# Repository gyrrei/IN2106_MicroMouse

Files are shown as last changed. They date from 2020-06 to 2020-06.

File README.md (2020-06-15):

# MicroMouse - Advanced Practical Course

IN2106 @TUM SS19 by Prof. Alexander Lenz. Achieved a 1.0 grade.

Master practical course - Micromouse: Designing an Educational Racing-Robot from Scratch. The purpose is for the students to build an electrical micro mouse from scratch and program it to explore a mace and find the fastest way to a goal.

The src has five folders:
- Bluetooth; describes the bluetooth module
- Code; the source code with headers and c files
- Notes; papers gathered and used throughout the project
- Micromouse_board; files describing the board design 
- Motormount; files describing the design of the motormounts

Read more about the course here: https://campus.tum.de/tumonline/wbLv.wbShowLVDetail?pStpSpNr=950367380&pSpracheNr=2

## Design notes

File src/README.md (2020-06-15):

# The source code
This project is organised as a practical course at the Technical University Munich for the students at the department of informatics. The purpose is for the students to build an electrical micro mouse from scratch and program it to explore a mace and find the fastest way to a goal.

### Here you find 5 folders:
- Bluetooth; describes the bluetooth module
- Code; the source code with headers and c files
- Notes; papers gathered and used throughout the project
- Micromouse_board; files describing the board design 
- Motormount; files describing the design of the motormounts

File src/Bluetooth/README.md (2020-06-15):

# Bluetooth laptop interface

## To run double-click:

	Bluetooth.jar 

## Use:

1. Select Bluetooth device
2. Select SERIAL service 
3. get UPDATE with pressing 'U'
   get periodic UPDATEs with pressing 'P'
   stop periodic UPDATEs with pressing 'Q'

## Requirements

Java 11

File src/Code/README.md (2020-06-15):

# Code

## Sensors

### ADC

takes the sensor input from AN0, 1 and 4 

### DMA

transfers these values to adcData[0], adcData[1] and adcData[2]

### Sensor

can return if there's a wall detected and how far away the walls are

## Motor

### PWM

Motors driving forward, backward, stop

### QEI

get the encoder signal -> calculating speed and distance

### Control

PID controler to keep the angular speed as it should
Speed of Motor 1 (negativ), Motor 2 (positiv) --> mounted the other way round

## Communication

## UART

can send String messages via bluetooth module

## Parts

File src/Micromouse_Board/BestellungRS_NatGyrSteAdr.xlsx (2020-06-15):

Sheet: Bestellung
Lieferant: RS
https://www.mouser.de/
 | Bestellnummer | Description | Need | Min order | Single price | Total price
 | 915-5193 | TDK, CGA SMD MLCC, Vielschicht Keramikkondensator X7S, 10μF ±10% / 16Vdc, 125°C, Gehäuse 0805 (2012M) | 2 | 20 | 0.24 € | 4.90 €
 | 885-1691 | Murata, GRM SMD MLCC, Vielschicht Keramikkondensator X5R, 22μF ±20% / 16Vdc, Gehäuse 0805 (2012M) | 2 | 20 | 0.29 € | 5.88 €
 | 825-6949 | Texas Instruments TPS62163DSGT Abwärtswandler, 2,25 MHz / 1A, WSON 8-Pin, Fest | 1 | 5 | 1.81 € | 9.05 €
 | 825-6945 | Texas Instruments TPS62162DSGT Abwärtswandler, 2,25 MHz / 1A, WSON 8-Pin, Fest | 1 | 5 | 1.81 € | 9.05 €
 | 123-3126 | TDK SPM-LR Drosselspule mit Metall-Kern geschirmt, 2,2 μH / ±20% 2,6A, 3012 Gehäuse | 2 | 10 | 0.30 € | 3.00 €
 | 435-6767 | Broadcom SMD LED grün 2,2 V, 170° rechteckige Linse 2012 / 0805 | 3 | 50 | 0.24 € | 12.25 €
 | 565-869 | Panasonic ERA Dünnschichtwiderstand, 150Ω ±0.1% 0,125W, 0805 | 1 | 5 | 0.29 € | 1.45 €
 | 740-8971 | Bourns CR0805 SMD Festwiderstand, 1kΩ ±1% 0,125W, 0805 | 1 | 50 | 0.03 € | 1.45 €
 | 679-1608 | Vishay CRCW SMD Dickschichtwiderstand, 62Ω ±1% 0,125W, 0805 | 1 | 50 | 0.04 € | 2.25 €
 | 773-8446 | Syfer Technology, Flexicap SMD MLCC, Vielschicht Keramikkondensator C0G, NP0, 22pF ±5% / 100Vdc, 125°C | 2 | 10 | 0.13 € | 1.34 €
 | 391-5371 | Susumu Co Dünnschichtwiderstand, 47kΩ ±0.5% 0,063W, 0603 | 1 | 100 | 0.02 € | 2.30 €
 | 708-2197 | 1N5819HW-7-F Schottky Diode, 40V / 1A, SOD-123 2-Pin | 9 | 25 | 0.25 € | 6.30 €
 | 135-9548 | C & K PTS645SM502 LFS Taster, Einpoliger Ein/Aus-Schalter (SPST) 50 mA, 6 x 6mm | 2 | 20 | 0.17 € | 3.38 €
 | 146-0786 | Sharp Reflektierender Sensor, Oberflächenmontage, 15cm, 27 x 13.2 x 12mm | 3 | 3 | 6.97 € | 20.91 €
 | 714-0613 | Motor Driver IC L293B, 1A PDIP 16-Pin 4,5 → 36 V | 1 | 1 | 3.21 € | 3.21 €
 | 174-4482 | KEMET, C0805 SMD MLCC, Vielschicht Keramikkondensator X7R, 100nF ±10% / 100Vdc, 125°C, Gehäuse 0805 | 4 | 100 | 0.11 € | 10.80 €
 | 136-6079 | AVX TPS SMD Tantal Elko, Kondensator, 10μF ±10%, 20Vdc, +125°C, Gehäuse 3528-21 | 1 | 10 | 0.64 € | 6.43 €
 | 740-8971 | Bourns CR0805 SMD Festwiderstand, 1kΩ ±1% 0,125W, 0805 | 2 | 50 | 0.03 € | 1.45 €
 | 671-0453 | PowerTrench FDN359BN N-Kanal MOSFET, 30 V / 2,7 A, 500 mW, SOT-23 3-Pin | 1 | 5 | 0.40 € | 2.02 €
 | 566-412 | Panasonic ERA Dünnschichtwiderstand, 180Ω ±0.1% 0,1W, 0603 | 1 | 5 | 0.29 € | 1.47 €
 |  |  |  |  | Gesamtsumme: | 108.89 €

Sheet: All info
 | Lieferant: RS
 | https://www.mouser.de/
Same hersteller no? | Mouser no. | RS no. | Part no. | Part description | Bestellnummer | Beschreibung | Only need | Menge | Einzelpreis | Gesamtpreis | Mouserlink
FALSE | dsPIC33FJ64MC804-H/PT | dsPIC33FJ64MC804-I/PT | Is this double? See dspic further down | uc | 666-8491 | Digitaler Signalprozessor 16bit 40MHz 16 KB 64 KB Flash, TQFP 44-Pin 9-Kanal x 10 Bit, 9-Kanal x 12 Bit ADC, 1 1 2 | 1 | 1 | 4.76 € | 4.76 € | https://www.mouser.de/ProductDetail/Microchip-Technology/dsPIC33FJ64MC804-H-PT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
FALSE | CGA4J1X7S1E106K125AC | CGA4J1X7S1C106K125AC | c1 | cap 10u | 915-5193 | TDK, CGA SMD MLCC, Vielschicht Keramikkondensator X7S, 10μF ±10% / 16Vdc, 125°C, Gehäuse 0805 (2012M) | 2 | 20 | 0.24 € | 4.90 € | https://www.mouser.de/ProductDetail/TDK/CGA4J1X7S1E106K125AC
FALSE | GRM219R61C226ME15K | GRM219R61C226ME15L | c2 | cap 22u | 885-1691 | Murata, GRM SMD MLCC, Vielschicht Keramikkondensator X5R, 22μF ±20% / 16Vdc, Gehäuse 0805 (2012M) | 2 | 20 | 0.29 € | 5.88 € | https://www.mouser.de/ProductDetail/Murata-Electronics/GRM219R61C226ME15K
FALSE | TPS62163DSGR | TPS62163DSGT | u1 | tps62163 | 825-6949 | Texas Instruments TPS62163DSGT Abwärtswandler, 2,25 MHz / 1A, WSON 8-Pin, Fest | 1 | 5 | 1.81 € | 9.05 € | https://www.mouser.de/ProductDetail/Texas-Instruments/TPS62163DSGR
FALSE | TPS62162QDSGRQ1 | TPS62162DSGT | u2 | tps62162 | 825-6945 | Texas Instruments TPS62162DSGT Abwärtswandler, 2,25 MHz / 1A, WSON 8-Pin, Fest | 1 | 5 | 1.81 € | 9.05 € | https://www.mouser.de/ProductDetail/Texas-Instruments/TPS62162QDSGRQ1
TRUE | VLS3012HBX-2R2M | VLS3012HBX-2R2M | L1,L2 | ind | 181-5236 | TDK VLS-HBX Drosselspule mit Metall-Kern geschirmt, 2,2 μH / ±20% 3.76A | 2 | 250 | 0.49 € | 122.50 € | https://www.mouser.de/ProductDetail/?qs=pfd5qewlna6oSgcfnWnTMg%3D%3D
 | Alternative with a bit higher max DC 8,2A | 7448991022 | L1,L2 | ind | 185-7300 | Würth WE-MCRI SMD Induktivität mit Sinterstahl-Kern geschirmt, 2,2 μH / ±20%, 21.5MHz 8,2A, SMT Gehäuse | 2 | 2 | 3.40 € | 6.80 €
FALSE | HSME-C170 | HSMG-C170 | led1,led2,led3 | leds | 435-6767 | Broadcom SMD LED grün 2,2 V, 170° rechteckige Linse 2012 / 0805 | 3 | 50 | 0.24 € | 12.25 € | https://www.mouser.de/ProductDetail/Broadcom-Avago/HSME-C170?qs=sGAEpiMZZMseGfSY3csMkcu5vLJdOE0s5hBoS5UZEy4%3D
FALSE | RT0805FRE13150RL | ERA6AEB151V | r1 | res 150 | 565-869 | Panasonic ERA Dünnschichtwiderstand, 150Ω ±0.1% 0,125W, 0805 | 1 | 5 | 0.29 € | 1.45 € | https://www.mouser.de/ProductDetail/Yageo/RT0805FRE13150RL
FALSE | CR0805-FX-62R0ELF | CR0805-FX-1001ELF | r2 | res 62 | 740-8971 | Bourns CR0805 SMD Festwiderstand, 1kΩ ±1% 0,125W, 0805 | 1 | 50 | 0.03 € | 1.45 € | https://www.mouser.de/ProductDetail/Bourns/CR0805-FX-62R0ELF
FALSE | FOXSDLF/160R-20/TR | CRCW080562R0FKEA | y1 | 16mhz osc | 679-1608 | Vishay CRCW SMD Dickschichtwiderstand, 62Ω ±1% 0,125W, 0805 | 1 | 50 | 0.04 € | 2.25 € | https://www.mouser.de/ProductDetail/Fox/FOXSDLF-160R-20-TR
FALSE |  | 0603Y1000220JCT | c5,c6 | cap 22pF | 773-8446 | Syfer Technology, Flexicap SMD MLCC, Vielschicht Keramikkondensator C0G, NP0, 22pF ±5% / 100Vdc, 125°C | 2 | 10 | 0.13 € | 1.34 € | https://de.rs-online.com/web/p/mehrschichtkeramikkondensatoren/7738446/
FALSE | RS2012P-473-D-T5-3 | RR0816P-473-D | r3 | res 47k | 391-5371 | Susumu Co Dünnschichtwiderstand, 47kΩ ±0.5% 0,063W, 0603 | 1 | 100 | 0.02 € | 2.30 € | https://www.mouser.de/ProductDetail/Susumu/RS2012P-473-D-T5-3
TRUE | 1N5819HW-7-F | 1N5819HW-7-F | d1..9 | diode | 708-2197 | 1N5819HW-7-F Schottky Diode, 40V / 1A, SOD-123 2-Pin | 9 | 25 | 0.25 € | 6.30 € | https://www.mouser.de/ProductDetail/Diodes-Incorporated/1N5819HW-7-F
FALSE | PTS647SM50SMTR2LFS | PTS645SM502LFS | s1,s2 | switch | 135-9548 | C & K PTS645SM502 LFS Taster, Einpoliger Ein/Aus-Schalter (SPST) 50 mA, 6 x 6mm | 2 | 20 | 0.17 € | 3.38 € | https://www.mouser.de/ProductDetail/CK/PTS647SM50SMTR2LFS
FALSE |  | GP2Y0A51SK0F | j3,j4,j5 | dist sens | 146-0786 | Sharp Reflektierender Sensor, Oberflächenmontage, 15cm, 27 x 13.2 x 12mm | 3 | 3 | 6.97 € | 20.91 € | https://de.rs-online.com/web/p/reflexions-lichtschranke/1460786/
TRUE | L293B | L293B | ic1 | hbridge | 714-0613 | Motor Driver IC L293B, 1A PDIP 16-Pin 4,5 → 36 V | 1 | 1 | 3.21 € | 3.21 € | https://www.mouser.de/ProductDetail/STMicroelectronics/L293B?qs=sGAEpiMZZMutXGli8Ay4kJRAwT4cotuJVvdz57xMrNY%3D
TRUE | C0805C104K1RECAUTO | C0805C104K1RECAUTO | c7,9,10,11 | dec cap 0.1u | 174-4482 | KEMET, C0805 SMD MLCC, Vielschicht Keramikkondensator X7R, 100nF ±10% / 100Vdc, 125°C, Gehäuse 0805 | 4 | 100 | 0.11 € | 10.80 € | https://www.mouser.de/ProductDetail/KEMET/C0805C104K1RECAUTO
TRUE | dsPIC33FJ64MC804-I/PT | dsPIC33FJ64MC804-I/PT |  | dspic | 666-8491 | Digitaler Signalprozessor 16bit 40MHz 16 KB 64 KB Flash, TQFP 44-Pin 9-Kanal x 10 Bit, 9-Kanal x 12 Bit ADC, 1 1 2 | 1 | 1 | 4.76 € | 4.76 € | https://www.mouser.de/ProductDetail/Microchip-Technology/dsPIC33FJ64MC804-I-PT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
FALSE | TPSB106K025T1800 | TPSB106K020R1000 | c8 | vcap 10uf | 136-6079 | AVX TPS SMD Tantal Elko, Kondensator, 10μF ±10%, 20Vdc, +125°C, Gehäuse 3528-21 | 1 | 10 | 0.64 € | 6.43 € | https://www.mouser.de/ProductDetail/AVX/TPSB106K025T1800
FALSE |  | CR0805-FX-1001ELF | r5,r7 | res 1k | 740-8971 | Bourns CR0805 SMD Festwiderstand, 1kΩ ±1% 0,125W, 0805 | 2 | 50 | 0.03 € | 1.45 € | https://de.rs-online.com/web/p/smd-widerstande/7408971/
FALSE |  | FDN359BN | t1 | mosfet | 671-0453 | PowerTrench FDN359BN N-Kanal MOSFET, 30 V / 2,7 A, 500 mW, SOT-23 3-Pin | 1 | 5 | 0.40 € | 2.02 € | https://de.rs-online.com/web/p/mosfet/6710453/?searchHistory=%7B%22enabled%22%3Atrue%7D
FALSE |  | ERA3AEB181V | r6 | res 180 | 566-412 | Panasonic ERA Dünnschichtwiderstand, 180Ω ±0.1% 0,1W, 0603 | 1 | 5 | 0.29 € | 1.47 €
 |  |  |  |  |  |  |  |  | Gesamtsumme: | 244.72 €

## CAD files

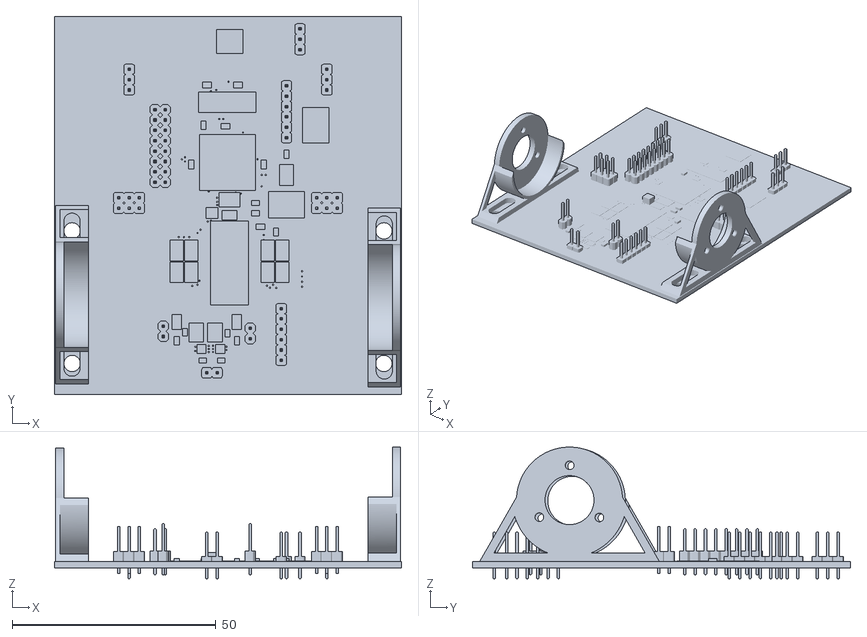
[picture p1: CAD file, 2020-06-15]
src/Motormount/micro_schematic v3.stl
85.1 x 92.7 x 32.3

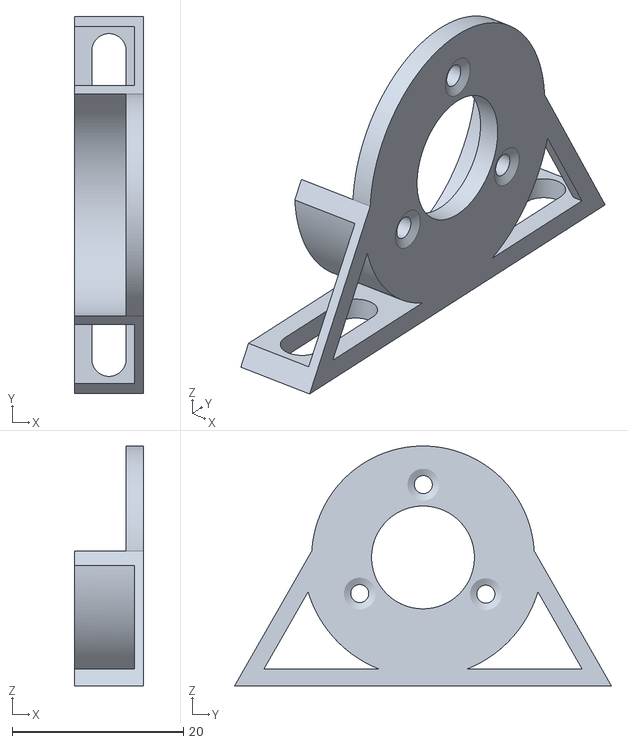
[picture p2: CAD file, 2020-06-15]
src/Motormount/mount.stl
8.00 x 44.0 x 28.0

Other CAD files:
src/Motormount/mount.f3d

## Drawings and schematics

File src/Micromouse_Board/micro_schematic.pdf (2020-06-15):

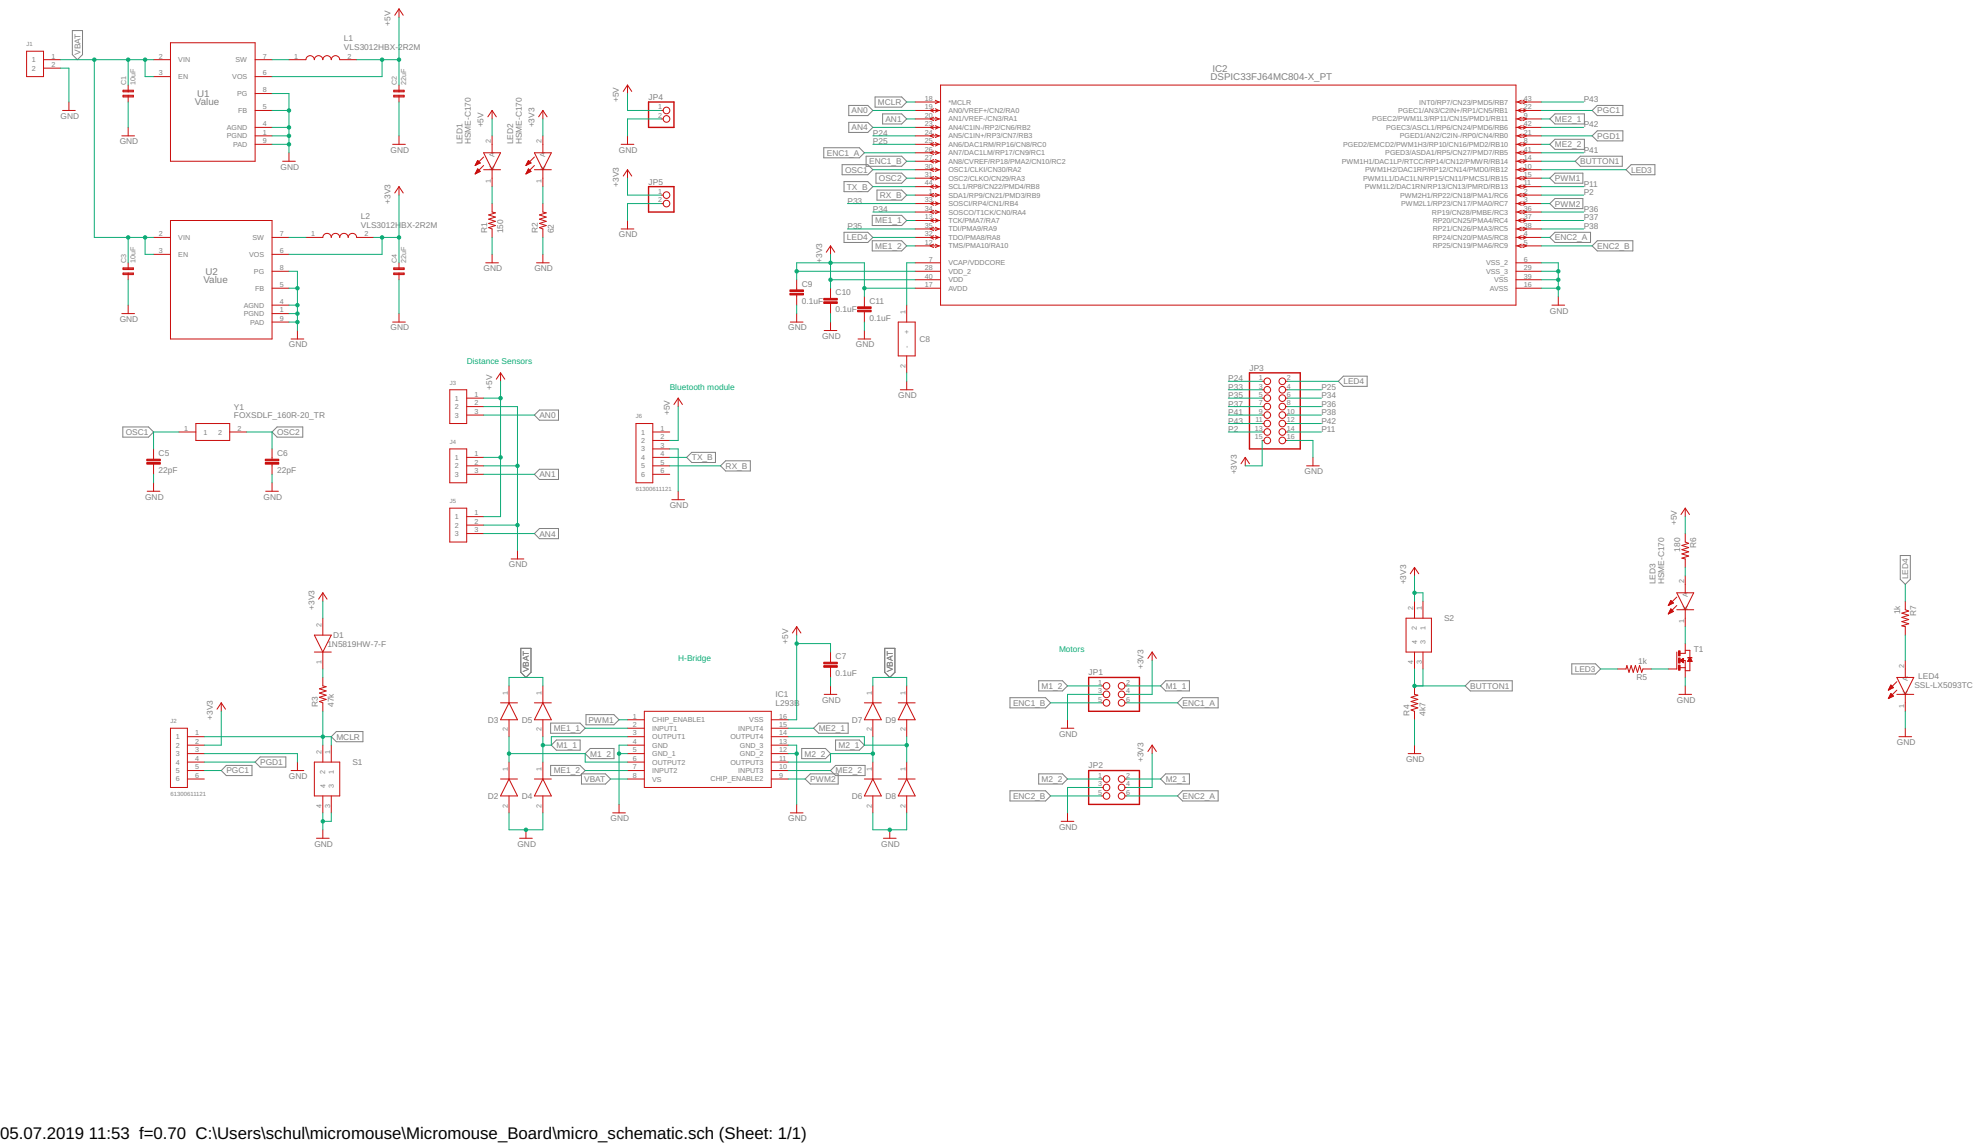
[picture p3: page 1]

05.07.2019 11:53 f=0.70 C:\Users\schul\micromouse\Micromouse_Board\micro_schematic.sch (Sheet: 1/1)

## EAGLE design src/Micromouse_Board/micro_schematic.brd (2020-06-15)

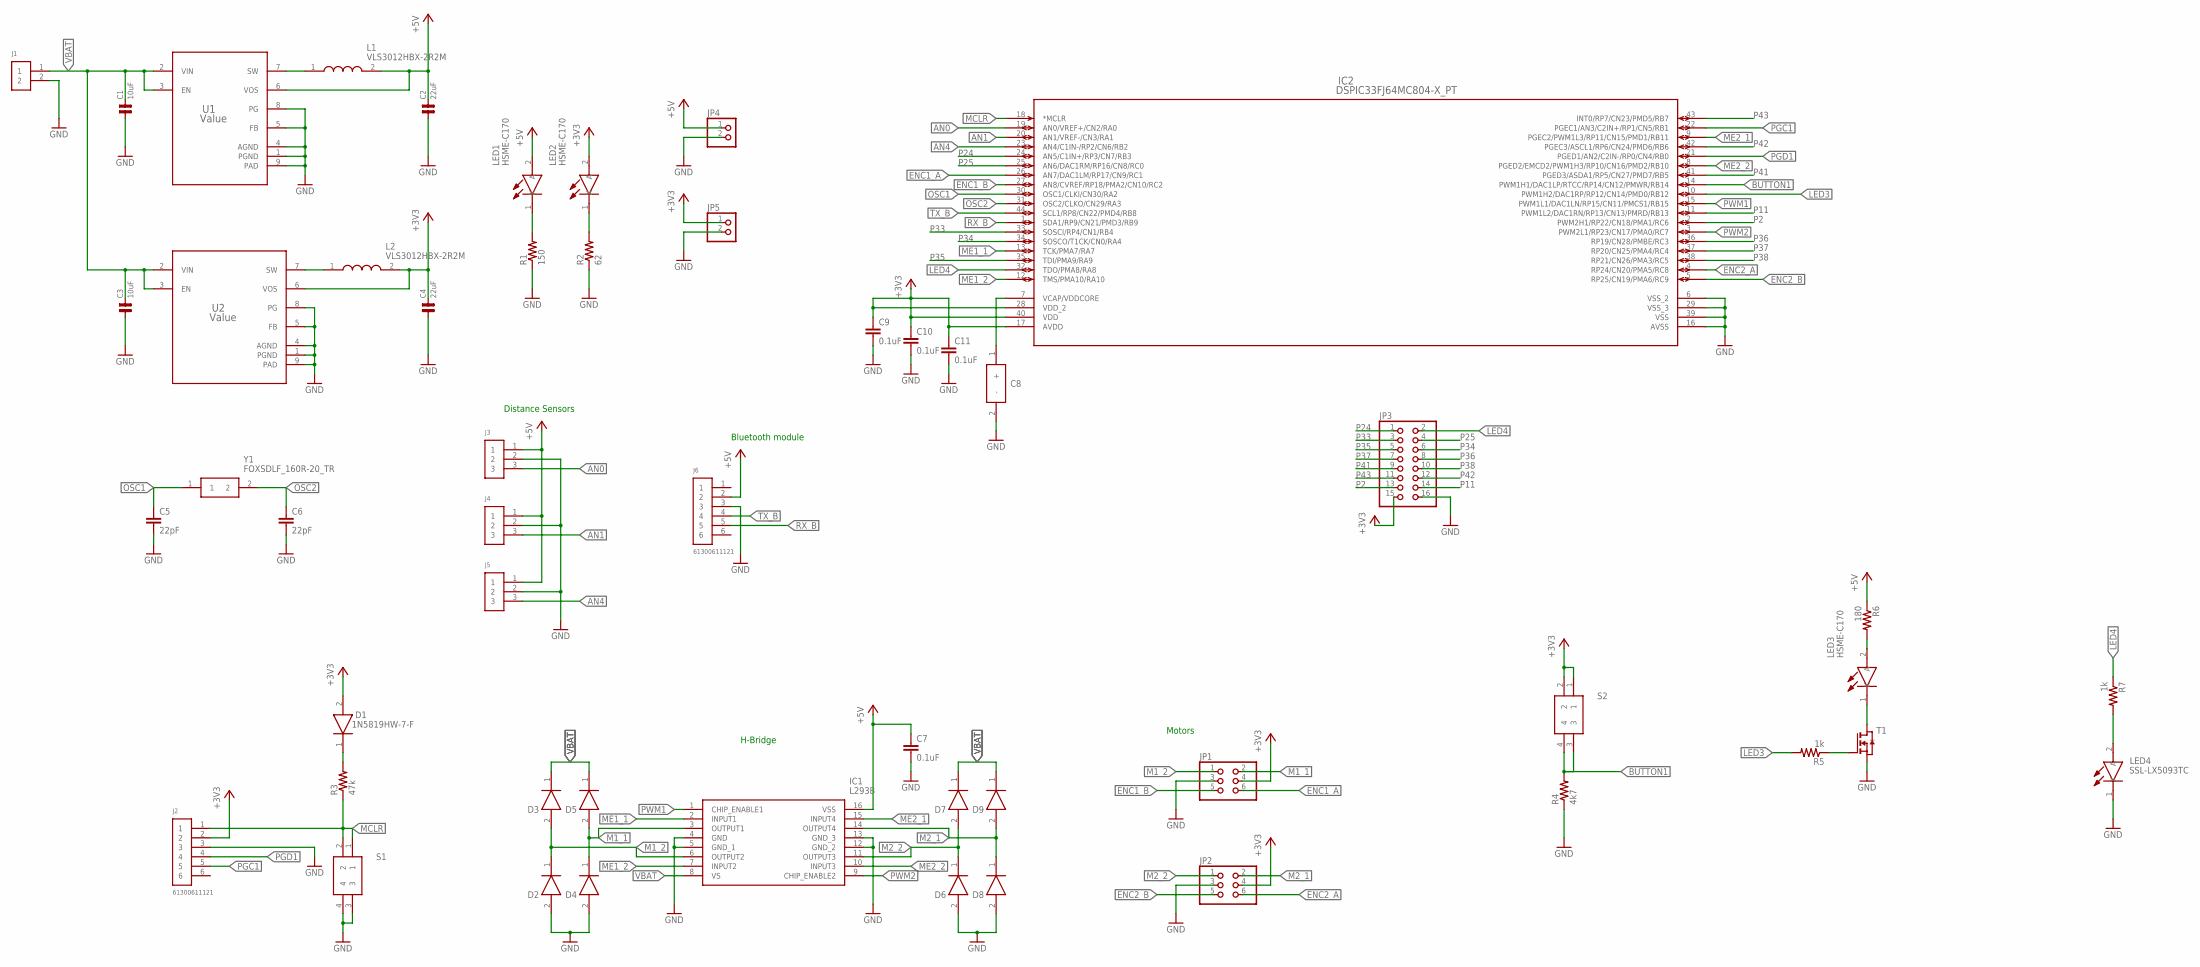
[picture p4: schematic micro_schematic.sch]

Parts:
C1, C3: 10uF; 0805
C2, C4: 22uF; 0805
C5, C6: 22pF; C0805
C7, C9, C10, C11: 0.1uF; C0805
C8: TPSB106K025T1800; DIONM3528X210N
D1, D2, D3, D4, D5, D6, D7, D8, D9: 1N5819HW-7-F; SOD3716X145N
IC1: L293B; DIP780W50P254L2000H510Q16N
IC2: DSPIC33FJ64MC804-X_PT; TQFP44_10X10MC
J1: 61300211121
J2, J6: 61300611121
J3, J4, J5: 61300311121
JP1, JP2: PINHD-2X3; 2X03
JP3: PINHD-2X8; 2X08
JP4, JP5: PINHD-1X2; 1X02
L1, L2: VLS3012HBX-2R2M; INDPM3030X120N
LED1, LED2, LED3: HSME-C170; LEDC2012X90N
LED4: SSL-LX5093TC; SSL-LX5093SGC/B
R1: 150; R0805
R2: 62; R0805
R3: 47k; R0805
R4: 4k7; R0805
R5, R7: 1k; R0805
R6: 180; R0805
S1, S2: PTS647SM50SMTR2LFS
T1: NMOSSOT23; SOT-23
U1, U2: Value; DSG0008A
Y1: FOXSDLF_160R-20_TR; FOXSDLF/240F-20

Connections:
+3V3: C4.2, C9.1, C10.1, C11.1, D1.2 (A), IC2.17 (AVDD), IC2.28 (VDD_2), IC2.40 (VDD), J2.2, JP1.4, JP2.4, JP3.15, JP5.1, L2.2, LED2.2 (A), S2.1, S2.2, U2.6 (VOS)
+5V: C2.2, C7.1, IC1.16 (VSS), J3.1, J4.1, J5.1, J6.2, JP4.1, L1.2, LED1.2 (A), R6.1, U1.6 (VOS)
AN0: IC2.19 (AN0/VREF+/CN2/RA0), J3.3
AN1: IC2.20 (AN1/VREF-/CN3/RA1), J4.3
AN4: IC2.23 (AN4/C1IN-/RP2/CN6/RB2), J5.3
BUTTON1: IC2.14 (PWM1H1/DAC1LP/RTCC/RP14/CN12/PMWR/RB14), R4.2, S2.3, S2.4
ENC1_A: IC2.26 (AN7/DAC1LM/RP17/CN9/RC1), JP1.6
ENC1_B: IC2.27 (AN8/CVREF/RP18/PMA2/CN10/RC2), JP1.5
ENC2_A: IC2.4 (RP24/CN20/PMA5/RC8), JP2.6
ENC2_B: IC2.5 (RP25/CN19/PMA6/RC9), JP2.5
GND: C1.1, C2.1, C3.1, C4.1, C5.2, C6.2, C7.2, C8.2 (-), C9.2, C10.2, C11.2, D2.2 (A), D4.2 (A), D6.2 (A), D8.2 (A), IC1.4 (GND), IC1.5 (GND_1), IC1.12 (GND_2), IC1.13 (GND_3), IC2.6 (VSS_2), IC2.16 (AVSS), IC2.29 (VSS_3), IC2.39 (VSS), J1.2, J2.3, J3.2, J4.2, J5.2, J6.3, JP1.3, JP2.3, JP3.16, JP4.2, JP5.2, LED4.1 (K), R1.1, R2.1, R4.1, S1.3, S1.4, T1.2 (S), U1.1 (PGND), U1.4 (AGND), U1.5 (FB), U1.8 (PG), U1.9 (PAD), U2.1 (PGND), U2.4 (AGND), U2.5 (FB), U2.8 (PG), U2.9 (PAD)
LED3: IC2.10 (PWM1H2/DAC1RP/RP12/CN14/PMD0/RB12), R5.2
LED4: IC2.32 (TDO/PMA8/RA8), JP3.2, R7.1
M1_1: D4.1 (K), D5.2 (A), IC1.3 (OUTPUT1), JP1.2
M1_2: D2.1 (K), D3.2 (A), IC1.6 (OUTPUT2), JP1.1
M2_1: D8.1 (K), D9.2 (A), IC1.14 (OUTPUT4), JP2.2
M2_2: D6.1 (K), D7.2 (A), IC1.11 (OUTPUT3), JP2.1
MCLR: IC2.18 (*MCLR), J2.1, R3.1, S1.1, S1.2
ME1_1: IC1.2 (INPUT1), IC2.13 (TCK/PMA7/RA7)
ME1_2: IC1.7 (INPUT2), IC2.12 (TMS/PMA10/RA10)
ME2_1: IC1.15 (INPUT4), IC2.9 (PGEC2/PWM1L3/RP11/CN15/PMD1/RB11)
ME2_2: IC1.10 (INPUT3), IC2.8 (PGED2/EMCD2/PWM1H3/RP10/CN16/PMD2/RB10)
unnamed: C8.1 (+), IC2.7 (VCAP/VDDCORE)
unnamed: LED2.1 (K), R2.2
unnamed: L1.1, U1.7 (SW)
unnamed: LED1.1 (K), R1.2
unnamed: L2.1, U2.7 (SW)
unnamed: R5.1, T1.3 (G)
unnamed: D1.1 (K), R3.2
unnamed: LED3.2 (A), R6.2
unnamed: LED4.2 (A), R7.2
unnamed: LED3.1 (K), T1.1 (D)
OSC1: C5.1, IC2.30 (OSC1/CLKI/CN30/RA2), Y1.1
OSC2: C6.1, IC2.31 (OSC2/CLKO/CN29/RA3), Y1.2
P2: IC2.2 (PWM2H1/RP22/CN18/PMA1/RC6), JP3.13
P11: IC2.11 (PWM1L2/DAC1RN/RP13/CN13/PMRD/RB13), JP3.14
P24: IC2.24 (AN5/C1IN+/RP3/CN7/RB3), JP3.1
P25: IC2.25 (AN6/DAC1RM/RP16/CN8/RC0), JP3.4
P33: IC2.33 (SOSCI/RP4/CN1/RB4), JP3.3
P34: IC2.34 (SOSCO/T1CK/CN0/RA4), JP3.6
P35: IC2.35 (TDI/PMA9/RA9), JP3.5
P36: IC2.36 (RP19/CN28/PMBE/RC3), JP3.8
P37: IC2.37 (RP20/CN25/PMA4/RC4), JP3.7
P38: IC2.38 (RP21/CN26/PMA3/RC5), JP3.10
P41: IC2.41 (PGED3/ASDA1/RP5/CN27/PMD7/RB5), JP3.9
P42: IC2.42 (PGEC3/ASCL1/RP6/CN24/PMD6/RB6), JP3.12
P43: IC2.43 (INT0/RP7/CN23/PMD5/RB7), JP3.11
PGC1: IC2.22 (PGEC1/AN3/C2IN+/RP1/CN5/RB1), J2.5
PGD1: IC2.21 (PGED1/AN2/C2IN-/RP0/CN4/RB0), J2.4
PWM1: IC1.1 (CHIP_ENABLE1), IC2.15 (PWM1L1/DAC1LN/RP15/CN11/PMCS1/RB15)
PWM2: IC1.9 (CHIP_ENABLE2), IC2.3 (PWM2L1/RP23/CN17/PMA0/RC7)
RX_B: IC2.1 (SDA1/RP9/CN21/PMD3/RB9), J6.5
TX_B: IC2.44 (SCL1/RP8/CN22/PMD4/RB8), J6.4
VBAT: C1.2, C3.2, D3.1 (K), D5.1 (K), D7.1 (K), D9.1 (K), IC1.8 (VS), J1.1, U1.2 (VIN), U1.3 (EN), U2.2 (VIN), U2.3 (EN)

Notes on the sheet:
Distance Sensors
Bluetooth module
H-Bridge
Motors

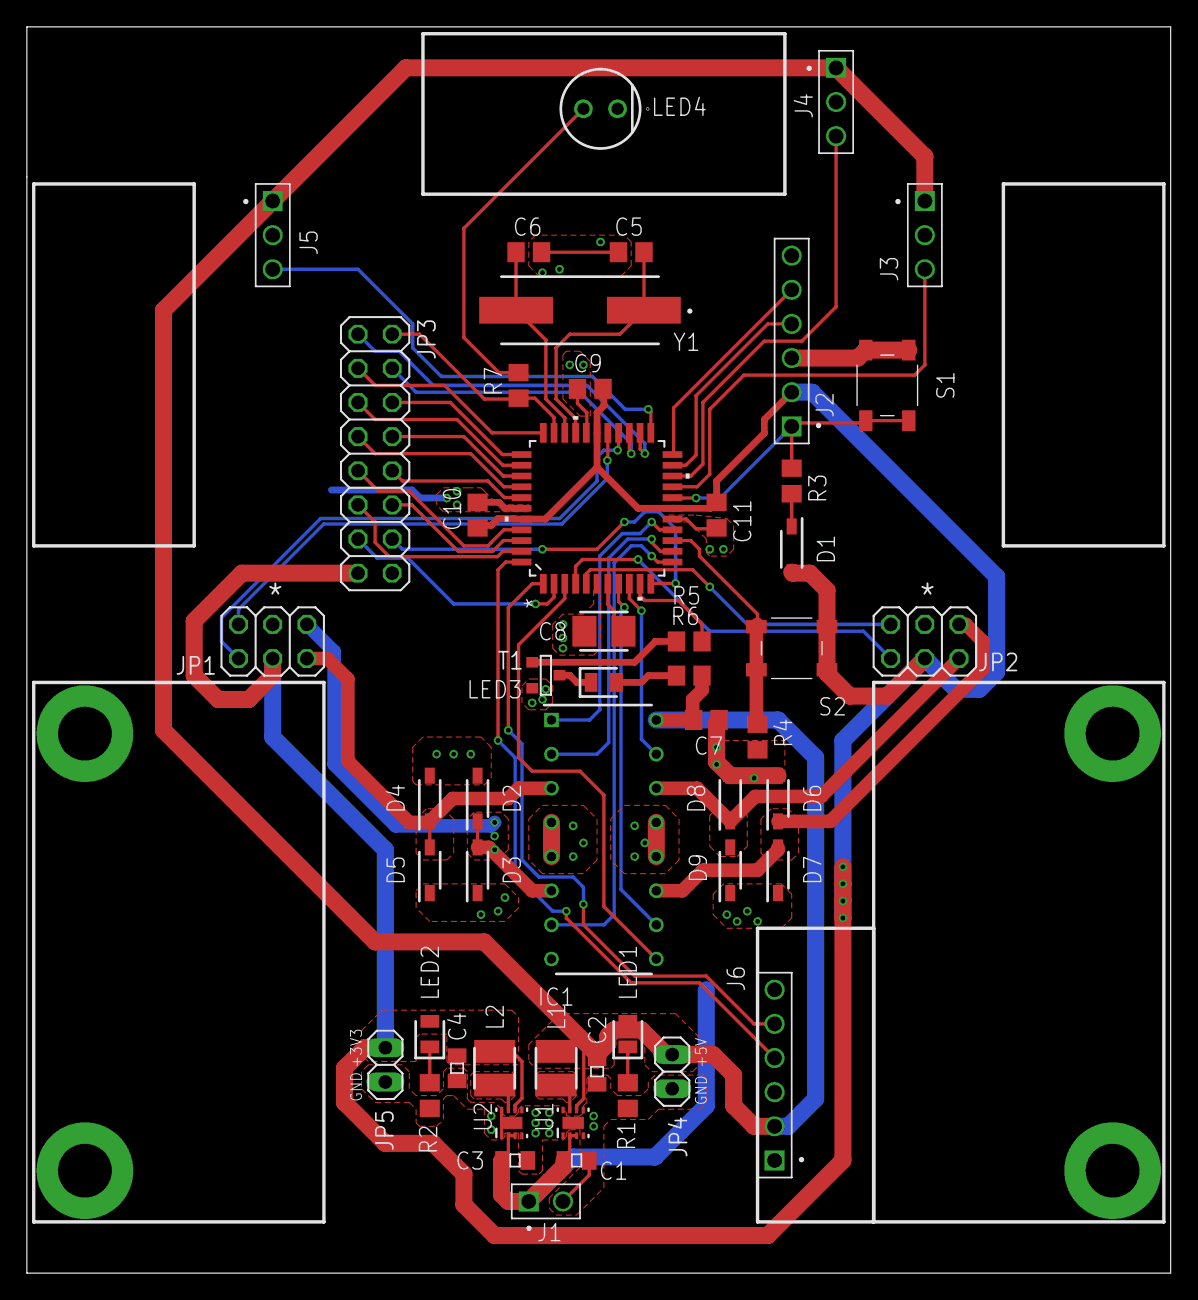
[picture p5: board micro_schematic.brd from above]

Board: 2 copper layers, 85.1 x 92.7 mm, 52 parts (0 on the bottom side), 54 nets.

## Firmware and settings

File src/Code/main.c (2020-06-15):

/*
 * File:   main.c
 * Author: a2-lenz
 *
 * Created on April 5, 2019, 11:20 AM
 */

// FBS
#pragma config BWRP = WRPROTECT_OFF // Boot Segment Write Protect (Boot Segment may be written)
#pragma config BSS = NO_FLASH       // Boot Segment Program Flash Code Protection (No Boot program Flash segment)

// FGS
#pragma config GWRP = OFF // General Code Segment Write Protect (User program memory is not write-protected)
#pragma config GSS = OFF  // General Segment Code Protection (User program memory is not code-protected)

// FOSCSEL
#pragma config FNOSC = PRIPLL // Oscillator Mode (Primary Oscillator (XT, HS, EC) w/ PLL)
#pragma config IESO = ON      // Internal External Switch Over Mode (Start-up device with FRC, then automatically switch to user-selected oscillator source when ready)

// FOSC
#pragma config POSCMD = HS    // Primary Oscillator Source (HS Oscillator Mode)
#pragma config OSCIOFNC = OFF // OSC2 Pin Function (OSC2 pin has clock out function)
#pragma config IOL1WAY = OFF  // Peripheral Pin Select Configuration (Allow Multiple Re-configurations)
#pragma config FCKSM = CSDCMD // Clock Switching and Monitor (Both Clock Switching and Fail-Safe Clock Monitor are disabled)

// FWDT
#pragma config WDTPOST = PS1  // Watchdog Timer Postscaler (1:1)
#pragma config WDTPRE = PR128 // WDT Prescaler (1:128)
#pragma config WINDIS = OFF   // Watchdog Timer Window (Watchdog Timer in Non-Window mode)
#pragma config FWDTEN = OFF   // Watchdog Timer Enable (Watchdog timer enabled/disabled by user software)

// FPOR
#pragma config FPWRT = PWR1 // POR Timer Value (Disabled)
#pragma config ALTI2C = ON  // Alternate I2C  pins (I2C mapped to SDA1/SCL1 pins)
#pragma config LPOL = ON    // Motor Control PWM Low Side Polarity bit (PWM module low side output pins have active-high output polarity)
#pragma config HPOL = ON    // Motor Control PWM High Side Polarity bit (PWM module high side output pins have active-high output polarity)
#pragma config PWMPIN = ON  // Motor Control PWM Module Pin Mode bit (PWM module pins controlled by PORT register at device Reset)

// FICD
#pragma config ICS = PGD1   // Comm Channel Select (Communicate on PGC1/EMUC1 and PGD1/EMUD1)
#pragma config JTAGEN = OFF // JTAG Port Enable (JTAG is Disabled)

// #pragma config statements should precede project file includes.
// Use project enums instead of #define for ON and OFF.
#include "xc.h"
#include "timer.h"
#include "gpio.h"
#include "uart.h"
#include "adc.h"
#include "dma.h"
#include "pwm.h"
#include "qei.h"
#include "control.h"
#include "maze.h"

#define IN_SIMULATION_MODE 0

//int dat[256];
int main(void)
{
    /*** oscillator setup --------------------------------------------------
    Here we are using PPL for 16MHz to generate 80MHz clock.
           * An instruction cycle is half of it so 40MHz clock (Tcycle = 25 ns)
    FCY = 0.5 * (16MHz*20/(2*2)) = 40 MIPS (40 mega instructions per second)
    ---------------------------------------------------------------------***/
    PLLFBD = 18;            //set PPL to M=20 (18+2) PG 145 datasheet
    CLKDIVbits.PLLPRE = 0;  //N1 = input/2  2 to 33
    CLKDIVbits.PLLPOST = 0; //N2 = output/2

    if (IN_SIMULATION_MODE != 1)
    {
        while (OSCCONbits.LOCK != 1)
            ; //Wait for PPL to lock
    }
    initIO();
    initUART();
    init_QEI(); // init QEI before timers cause one of the timer calls needs it
    initTimer1(6250); //6250 gives 10ms timer interrupt, based on a 1.6 us base = 40MIPS with 64 prescaler
    initTimer2(6250); //2600 gives 4.16ms timer interrupt, based on 40MIPs with 64 prescaler
    initDmaChannel4();
    setupADC1();
    startADC1();
    init_PWM();
    startTimer1();
    startTimer2();
<<<<<<< HEAD
     //comm = 't';
    //wait(500);
    //flag = 0;
    //computes shortest path to (X;Y)
    //int X = 1, Y = 1;
    //shortestPath(X, Y, DISTANCE(last[X][Y]));
    //drives the shortest Path
    //driveSP();
=======
     
>>>>>>> master
    while(1){
        if(BUTTON) {
            explore();
        }
    };
    return 0;
}

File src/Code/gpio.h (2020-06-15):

/* 
 * File:   gpio.h
 * Author: a2-lenz
 *
 * Created on April 5, 2019, 11:31 AM
 */

#ifndef GPIO_H
#define	GPIO_H
#include "xc.h"

#define BUTTON PORTBbits.RB14 //BUTTON

#define LED_Back  LATBbits.LATB12 
#define LED_Front LATAbits.LATA8 
#define LED_Left LATBbits.LATB3 //Left LED
#define LED_Right LATCbits.LATC0 
 
//******* Define two bits as output bits for the first H-Bridge
#define HBRIDGE1 LATAbits.LATA7 
#define HBRIDGE2 LATAbits.LATA10 

//******* Define two bits as output bits for the second H-Bridge
#define HBRIDGE4 LATBbits.LATB11 
#define HBRIDGE3 LATBbits.LATB10


void initIO();
#endif	/* GPIO_H */

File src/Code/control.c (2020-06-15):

/*
 * File:   motor_control.c
 * Author: Steff
 *
 * Created on 19. Juni 2019, 16:39
 * Changed by Adrian on 5-7-2019
 */


#include "xc.h"
#include "pwm.h"
#include "gpio.h"
#include "qei.h"
#include "control.h"
//#include "uart.h"
#include "sensor.h"
#include "timer.h"

<<<<<<< HEAD
int motor1_wanted_speed = 1;
=======
int motor1_wanted_speed = 1.2;
>>>>>>> master
int motor2_wanted_speed = 1;

int flag = 0;

float correction = 0.7;
float correction2 = 0.2;

PID_Controller pos_control_left = {.kp = 1, .ki = 0, .kd = 0,
                                    .top_lim = 30, .bot_lim = -30};
PID_Controller pos_control_right = {.kp = 1, .ki = 0, .kd = 0,
                                    .top_lim = 30, .bot_lim = -30};
<<<<<<< HEAD
PID_Controller vel_control_left = {.kp =50, .ki = 0, .kd = 1,
                                    .top_lim = 2000, .bot_lim = -2000};
PID_Controller vel_control_right = {.kp = 50, .ki = 0, .kd = 1,
                                    .top_lim = 2000, .bot_lim = -2000};
=======
PID_Controller vel_control_left = {.kp =50, .ki = 5, .kd = 1,
                                    .top_lim = 2000, .bot_lim = -2000,
                                    .int_lim = 100};
PID_Controller vel_control_right = {.kp = 50, .ki = 5, .kd = 1,
                                    .top_lim = 2000, .bot_lim = -2000,
                                    .int_lim = 100};
>>>>>>> master

void test_go_straight(int speed) {
    vel_control_left.target = (long)speed;
    vel_control_right.target = (long)speed;
    evaluate_controller(&vel_control_left, current_speed1);
    evaluate_controller(&vel_control_right, current_speed2);
    //sendNameValue("val", vel_control_left.value);
    drive_motor('L', vel_control_left.value);
    drive_motor('R', vel_control_right.value);
}


/*Here is another try to a more general and generic version of the PID that
 will probably work nicer in the controller cascade*/

void evaluate_controller(PID_Controller *controller, long int current_control_value) {
    
    (*controller).error = (*controller).target - current_control_value ;
    
    (*controller).integral = (*controller).integral + (*controller).error;
    
    if ((*controller).integral > (*controller).int_lim) {
        (*controller).integral = (*controller).int_lim;
    }
    
    (*controller).derivative = (*controller).error - (*controller).last_error;
    
    (*controller).last_error = (*controller).error;
    
    (*controller).value = (int)((*controller).kp * (*controller).error) + 
            ((*controller).ki * (*controller).integral) + 
            ((*controller).kd * (*controller).derivative);
    
    if ((*controller).value > (*controller).top_lim) {
        (*controller).value = (*controller).top_lim;
    } else if ((*controller).value < (*controller).bot_lim) {
        (*controller).value = (*controller).bot_lim;
    }
 
}

void motor_control() {
    
    evaluate_controller(&pos_control_left, (long)(longpos1 + POS1CNT));
    evaluate_controller(&pos_control_right, (long)(longpos2 + POS2CNT));
    
    vel_control_left.target = pos_control_left.value;
    vel_control_right.target = pos_control_right.value;
    
    /*if (flag == 1 && frontWall() && distance('f')<= 20) {
        if (distance('f') != -1) {
            
            fast_stop_motor('l');
            fast_stop_motor('r');
            flag = 0;
        }
    } else */
    
    
    
    if (flag == 1 || flag == 7) {
        int dist_front = distance('f');
        if (frontWall() && dist_front != -1) {
            approach_wall();
            flag = 10;
        }
     else if (flag == 1 && (rightWall() || leftWall())) {
        int dist_left = distance('l');
        if (dist_left == -1) {
            dist_left = 0;
        }
        int dist_right = distance('r');
        if (dist_right == -1) {
            dist_right = 0;
        }
        int dist_diff = dist_left - dist_right;
        if (rightWall() && leftWall()) {
            vel_control_left.target -= (int)(correction*dist_diff);
            vel_control_right.target += (int)(correction*dist_diff);
        } else if (rightWall()) {
<<<<<<< HEAD
            int dist_miss = dist_right - 25;
            //vel_control_left.target += (int)(correction2*dist_miss);
            vel_control_right.target -= (int)(correction2*dist_miss);
        } else {
            int dist_miss = dist_left - 25;
            vel_control_left.target -= (int)(correction2*dist_miss);
            //vel_control_right.target += (int)(correction2*dist_miss);
=======
            int dist_miss = dist_right - 30;
            vel_control_left.target += (int)(correction2*dist_miss);
            vel_control_right.target -= (int)(correction2*dist_miss);
        } else {
            int dist_miss = dist_left - 30;
            vel_control_left.target -= (int)(correction2*dist_miss);
            vel_control_right.target += (int)(correction2*dist_miss);
>>>>>>> master
        }
    }
    }
    
    evaluate_controller(&vel_control_left, (long)current_speed1);
    evaluate_controller(&vel_control_right, (long)current_speed2);
    
    drive_motor('L', vel_control_left.value);
    drive_motor('R', vel_control_right.value);     
}

void go_one_cell() {
    
    /*Given we take the big wheels, the number to set dist roughly calculates as:
    d*112 ; where d is the distance to be travelled in cm
     
    To go more than one cell ahead, you have to set the flag to 0 manually and
    then call go_one_cell() again, otherwise it will only go one cell ahead*/
    
    if (flag != 1 && flag != 10) {
        
        int d = 2000;
    
        GET_ENCODER_VALUE_1(current_pos1);
        GET_ENCODER_VALUE_2(current_pos2);
    
        pos_control_left.target = current_pos1 + d;
        pos_control_right.target = current_pos2 + d;
    
        flag = 1;
    }
}

void turn_right() {
    
    if (flag != 2) {
        
        int t = 924;
    
        GET_ENCODER_VALUE_1(current_pos1);
        GET_ENCODER_VALUE_2(current_pos2);

<<<<<<< HEAD
        pos_control_left.target = current_pos1 + 924;
        pos_control_right.target = current_pos2 - 924;
=======
        pos_control_left.target = current_pos1 + t;
        pos_control_right.target = current_pos2 - t;
>>>>>>> master

        flag = 2;
    }
}

void turn_left() {
    
    if (flag != 3) {
        
        int t = 924;

        GET_ENCODER_VALUE_1(current_pos1);
        GET_ENCODER_VALUE_2(current_pos2);

<<<<<<< HEAD
        pos_control_left.target = current_pos1 - 924;
        pos_control_right.target = current_pos2 + 924;
=======
        pos_control_left.target = current_pos1 - t;
        pos_control_right.target = current_pos2 + t;
>>>>>>> master

        flag = 3;
    }
}
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

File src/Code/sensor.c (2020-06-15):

#include "dma.h"
#include "uart.h"
#include "stdio.h"
#include <stdlib.h>



/** 
 *  returns approximated distance in mm for FRONT sensor
 *  distance 10-60mm in 5mm steps!!! Lower than 10mm gives weird values and collision gives -1
 *  returns -1 for to far
*/
int distance(char sensor){
    int ret, val;
    if (sensor == 'f')
        val = adcData[1];
    else if(sensor == 'r')
        val = adcData[0];
    else
        val = adcData[2];
    
            if (val > 3000) {
                ret = 10;
            } else {
                if (val > 2700) {
                    ret = 15;
                } else {
                    if (val > 2300) {
                        ret = 20;
                    } else {
                        if (val > 2000) {
                            ret = 25;
                        } else {
                            if (val > 1800) {
                                ret = 30;
                            } else {
                                if (val > 1600) {
                                    ret = 35;
                                } else {
                                    if (val > 1400) {
                                        ret = 40;
                                    } else {
                                        if (val > 1300) {
                                            return 45;
                                        } else {
                                            if (val > 1200) {
                                                ret = 50;
                                            } else {
                                                if (val > 1100) {
                                                    ret = 55;
                                                } else {
                                                    if (val > 1000) {
                                                        ret = 60;
                                                    } 
                                                    else {
                                                        ret = -1;
                                                    }
                                                }
                                            }
                                        }
                                    }
                                }
                            }
                        }
                    }
                }
            }
    return ret;
}

/** 
 *  returns 0 for no wall 1 for wall on the right side
*/
int rightWall(){
    if (adcData[0] < 1000 || adcData[0] > 3300)
        return 0;
    return 1;
}

/** 
 *  returns 0 for no wall 1 for wall on the left side
*/
int leftWall(){
    if (adcData[2] < 1000 || adcData[2] > 3300)
        return 0;
    return 1;
}

/** 
 *  returns 0 for no wall 1 for wall on the left side
*/
int frontWall(){
    if (adcData[1] < 1000 || adcData[1] > 3300)
        return 0;
    return 1;
}
/** 
 *  returns 0 for yes, -1 for too much on the left, 1 for too much on the right
*/
int middle(){
    int difference = adcData[0] - adcData[2];
    if (difference < 200 && difference > -200)
        return 0;
    if (difference <= -200)
        return -1;
    return 1;
}
